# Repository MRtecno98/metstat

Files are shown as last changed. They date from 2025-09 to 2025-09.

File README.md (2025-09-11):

# Metstat
A fully autonomous, unattended, solar-powered, IoT weather probe with mesh networking capabilities.

<br>


## Hardware stack
| Component  | Part | Notes |
| - | - | - |
| MCU | `STM32L4A6AG` | Low power MCU with small package size, decent connectivity and hardware acceleration for crypto algorithms |
| Power Supply  | `SPV1050` | Integrated energy harvester with Max Power Point Tracking. Managing intake from solar panels and LiPo storage |
| `TODO` | `TODO` | `TODO` |

## Firmware stack
Written in C++, runs on the standard STM32 [HAL](https://www.st.com/resource/en/user_manual/um1725-description-of-stm32f4-hal-and-lowlayer-drivers-stmicroelectronics.pdf) 
using [CubeMX](https://www.st.com/en/development-tools/stm32cubemx.html) (standard runtime for STM32s).

## Technical description
`todo`

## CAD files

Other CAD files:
metstat.SLDASM
pcb/main/main.step
metstat_mid.SLDPRT
metstat_cap.SLDPRT
legacy/mestat.SLDASM
legacy/wht_asm.SLDASM
legacy/mestat_part.SLDPRT
legacy/wht_side.SLDPRT
legacy/mestat.SLDDRW
stl/metstat_cap.STL
stl/metstat_mid.STL

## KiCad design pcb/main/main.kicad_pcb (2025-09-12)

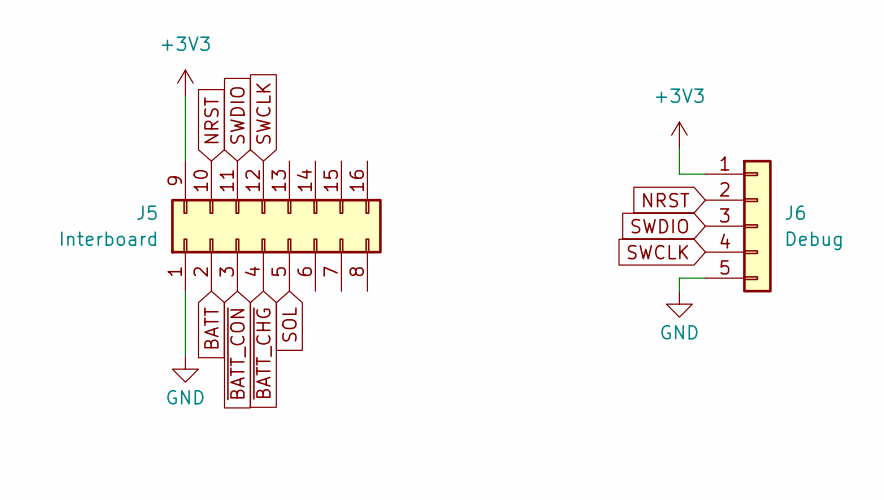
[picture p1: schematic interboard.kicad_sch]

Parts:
J5: Interboard; PinSocket_2x08_P2.54mm_Vertical
J6: Debug; PinHeader_1x05_P2.54mm_Horizontal

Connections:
+3V3: J5.9, J6.1; also elsewhere on the board
BATT: J5.2; also elsewhere on the board
GND: J5.1, J6.5; also elsewhere on the board
NRST: J5.10, J6.2; also elsewhere on the board
SOL: J5.5; also elsewhere on the board
SWCLK: J5.12, J6.4; also elsewhere on the board
SWDIO: J5.11, J6.3; also elsewhere on the board
~BATT_CHG: J5.4; also elsewhere on the board
~BATT_CON: J5.3; also elsewhere on the board

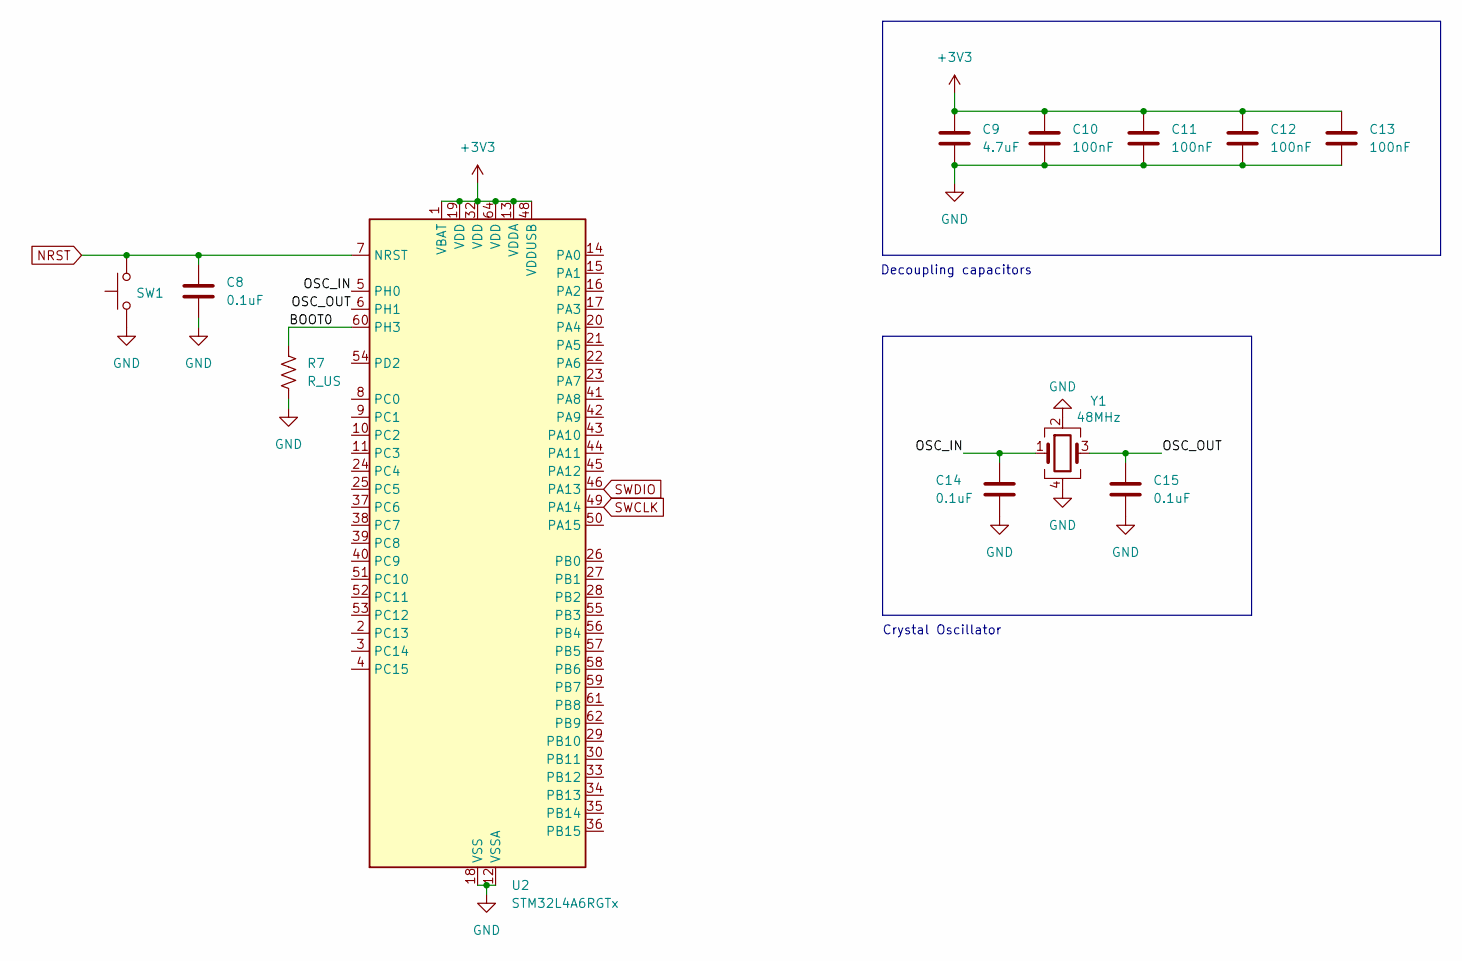
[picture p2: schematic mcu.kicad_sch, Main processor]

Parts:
C8, C14, C15: 0.1uF; C_0603_1608Metric_Pad1.08x0.95mm_HandSolder
C9: 4.7uF; C_0603_1608Metric_Pad1.08x0.95mm_HandSolder
C10, C11, C12, C13: 100nF; C_0603_1608Metric_Pad1.08x0.95mm_HandSolder
R7: R_US; R_0603_1608Metric_Pad0.98x0.95mm_HandSolder
SW1: SW_Push; SW_PUSH_6mm_H5mm
U2: STM32L4A6RGTx; LQFP-64_10x10mm_P0.5mm
Y1: 48MHz; Crystal_SMD_2016-4Pin_2.0x1.6mm

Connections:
+3V3: C9.1, C10.1, C11.1, C12.1, C13.1, U2.1 (VBAT), U2.13 (VDDA), U2.19 (VDD), U2.32 (VDD), U2.48 (VDDUSB), U2.64 (VDD); also elsewhere on the board
/MCU/BOOT0: R7.1, U2.60 (PH3)
/MCU/OSC_IN: C14.1, U2.5 (PH0), Y1.1
/MCU/OSC_OUT: C15.1, U2.6 (PH1), Y1.3
GND: C8.2, C9.2, C10.2, C11.2, C12.2, C13.2, C14.2, C15.2, R7.2, SW1.1, U2.12 (VSSA), U2.18 (VSS), U2.31 (VSS), U2.47 (VSS), U2.63 (VSS), Y1.2, Y1.4; also elsewhere on the board
NRST: C8.1, SW1.2, U2.7 (NRST); also elsewhere on the board
SWCLK: U2.49 (PA14); also elsewhere on the board
SWDIO: U2.46 (PA13); also elsewhere on the board

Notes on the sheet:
Crystal Oscillator
Decoupling capacitors

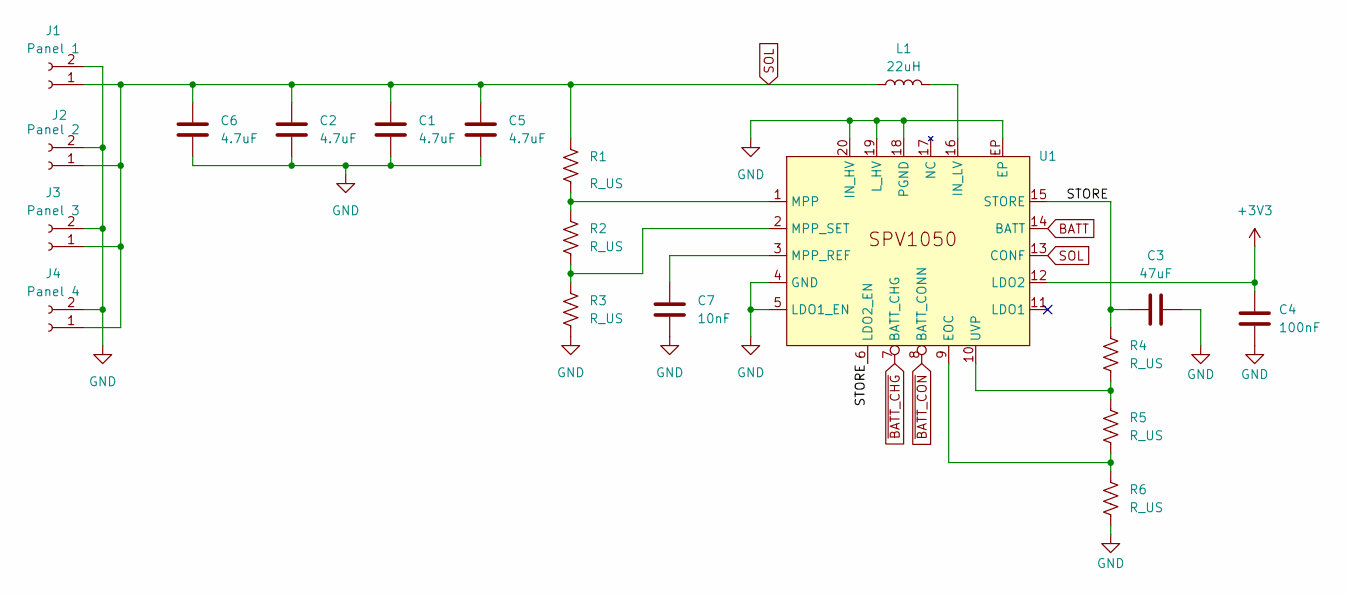
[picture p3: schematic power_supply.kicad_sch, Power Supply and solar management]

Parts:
C1, C2, C5, C6: 4.7uF; C_0603_1608Metric_Pad1.08x0.95mm_HandSolder
C3: 47uF; C_0603_1608Metric_Pad1.08x0.95mm_HandSolder
C4: 100nF; C_0603_1608Metric_Pad1.08x0.95mm_HandSolder
C7: 10nF; C_0603_1608Metric_Pad1.08x0.95mm_HandSolder
J1: Panel 1; Molex_PicoBlade_53261-0271_1x02-1MP_P1.25mm_Horizontal
J2: Panel 2; Molex_PicoBlade_53261-0271_1x02-1MP_P1.25mm_Horizontal
J3: Panel 3; Molex_PicoBlade_53261-0271_1x02-1MP_P1.25mm_Horizontal
J4: Panel 4; Molex_PicoBlade_53261-0271_1x02-1MP_P1.25mm_Horizontal
L1: 22uH; L_0603_1608Metric_Pad1.05x0.95mm_HandSolder
R1, R2, R3, R4, R5, R6: R_US; R_0603_1608Metric_Pad0.98x0.95mm_HandSolder
U1: SPV1050

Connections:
+3V3: C4.2, U1.12 (LDO2); also elsewhere on the board
/Power Supply/STORE: C3.2, R4.1, U1.6 (LDO2_EN), U1.15 (STORE)
BATT: U1.14 (BATT); also elsewhere on the board
GND: C1.2, C2.2, C3.1, C4.1, C5.2, C6.2, C7.2, J1.2, J2.2, J3.2, J4.2, R3.2, R6.2, U1.4 (GND), U1.5 (LDO1_EN), U1.18 (PGND), U1.19 (L_HV), U1.20 (IN_HV), U1.EP; also elsewhere on the board
unnamed: R5.2, R6.1, U1.9 (EOC)
unnamed: L1.2, U1.16 (IN_LV)
unnamed: R1.2, R2.1, U1.1 (MPP)
unnamed: C7.1, U1.3 (MPP_REF)
unnamed: R2.2, R3.1, U1.2 (MPP_SET)
unnamed: R4.2, R5.1, U1.10 (UVP)
SOL: C1.1, C2.1, C5.1, C6.1, J1.1, J2.1, J3.1, J4.1, L1.1, R1.1, U1.13 (CONF); also elsewhere on the board
~BATT_CHG: U1.7 (BATT_CHG); also elsewhere on the board
~BATT_CON: U1.8 (BATT_CONN); also elsewhere on the board

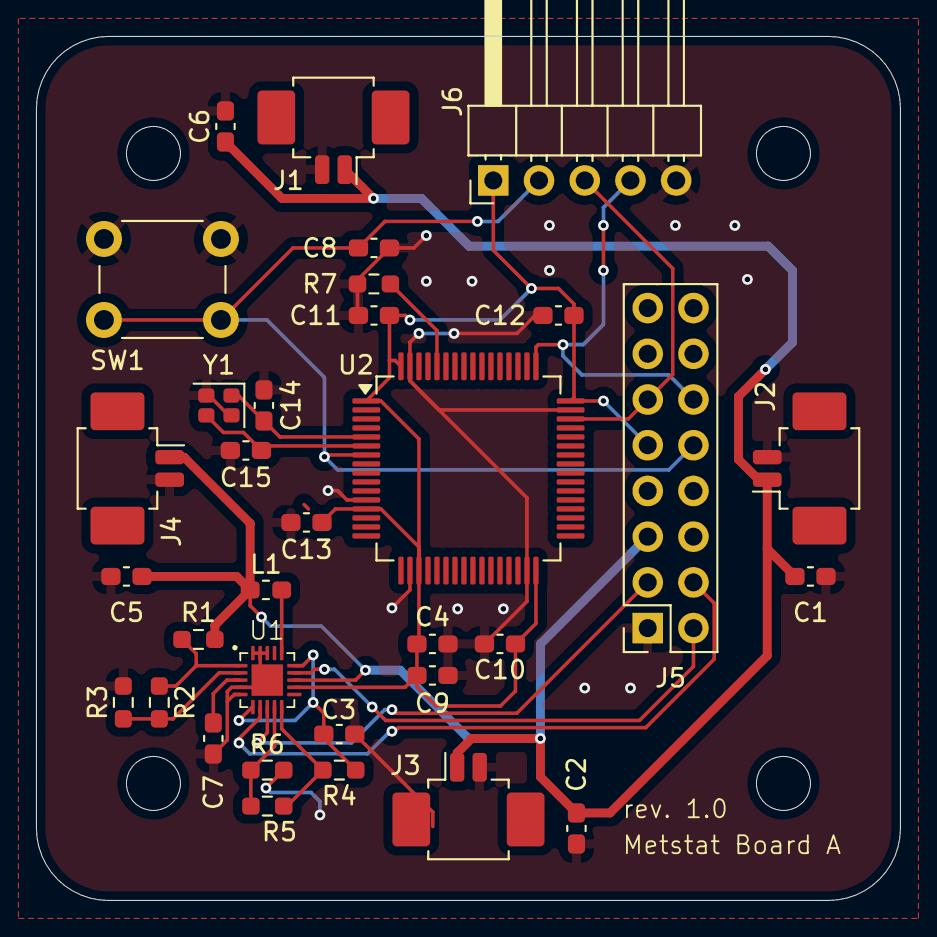
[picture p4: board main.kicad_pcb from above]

Board: 2 copper layers, 48.0 x 48.0 mm, 33 parts (0 on the bottom side), 19 nets.

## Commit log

2025-09-05 mechanical: update pcb fasteners to M3
    Now everything has the same screw size
    [metstat.SLDASM, metstat_cap.SLDPRT]
2025-09-09 mechanical: increase mid wall thickness to 8mm
    got issue during 3d printing and also it was way too low in general
    [metstat.SLDASM, metstat_cap.SLDPRT, metstat_mid.SLDPRT]
2025-09-11 add panel models, add M3 fastener models
    [metstat.SLDASM]
2025-09-11 mechanical: add m3 pcb fastener models
    [metstat.SLDASM]
2025-09-11 mechanical: update stl models
    [metstat.3mf, metstat.STL, metstat_cap.STL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]
2025-09-12 pcb: add mounting holes, move debug connector
    [main.kicad_pcb, main.step, power_supply.kicad_sch]
2025-09-12 mechanical: add main pcb to assembly
    [metstat.SLDASM]
